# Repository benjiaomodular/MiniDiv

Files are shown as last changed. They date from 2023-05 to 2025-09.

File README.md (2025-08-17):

# MiniDiv
[][cc-by-sa]

A simple clock divider based on [HAGIWO's  design](https://note.com/solder_state/n/n7979cda44dcb).

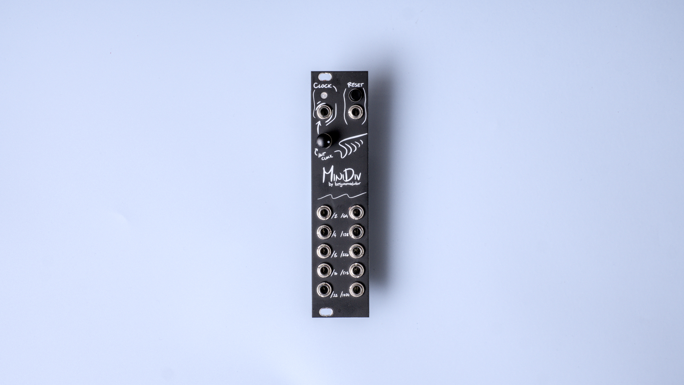
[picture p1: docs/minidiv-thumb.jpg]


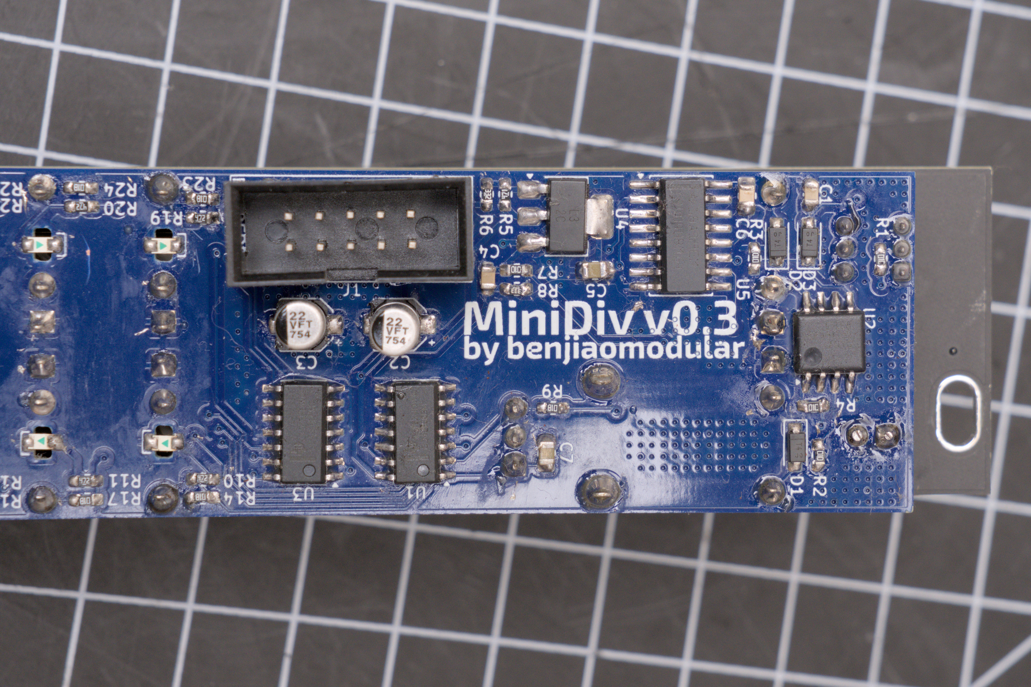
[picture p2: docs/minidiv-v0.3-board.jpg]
MiniDiv Photo


## Schematics
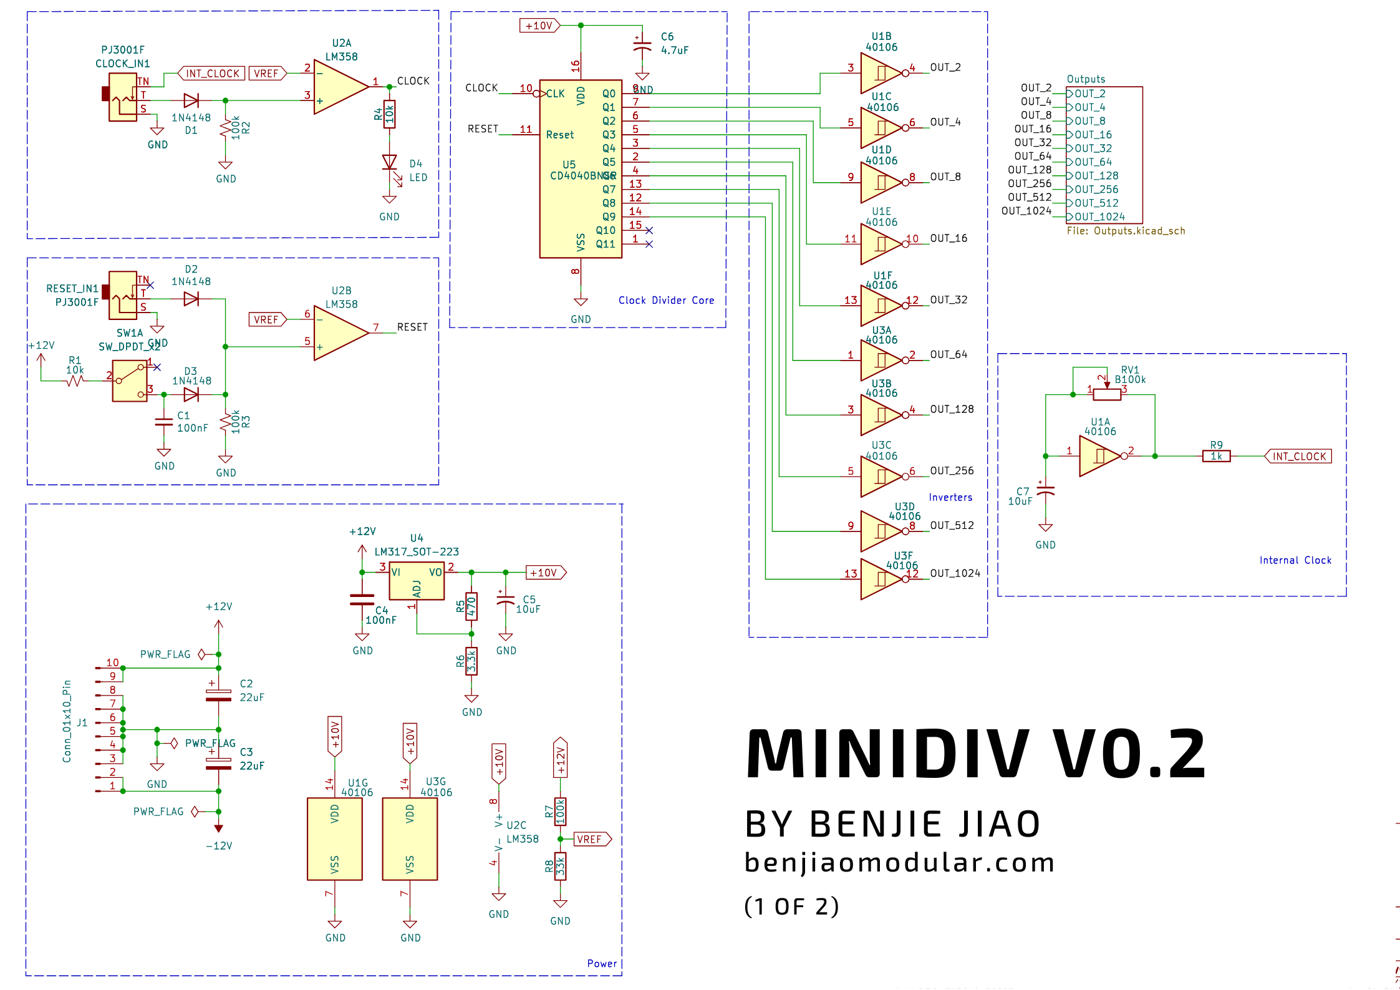
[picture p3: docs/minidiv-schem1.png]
MiniDiv Schematics

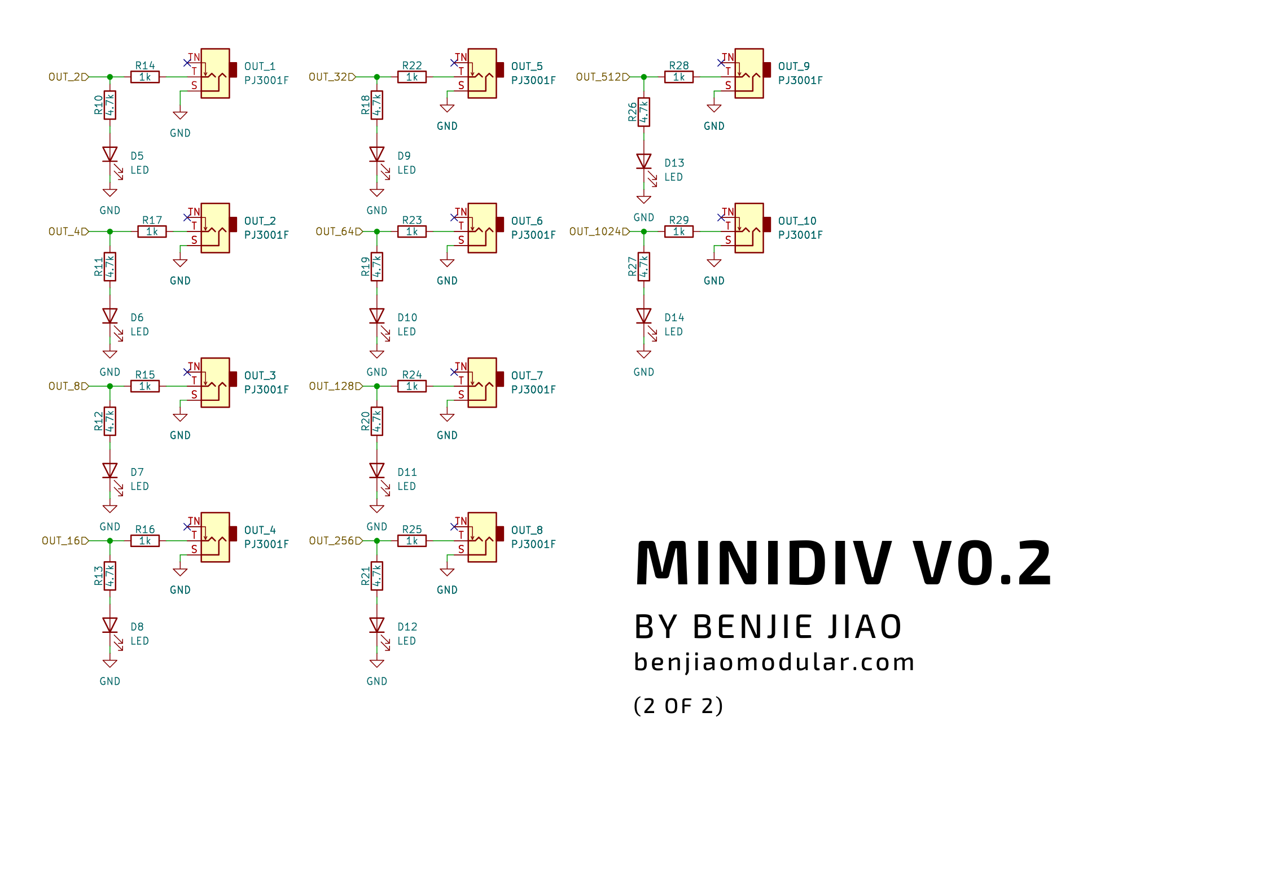
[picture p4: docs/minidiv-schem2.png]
MiniDiv Schematics


Project sponsored by [PCBWay](https://pcbway.com).

See my full docs on my website: https://benjiaomodular.com/post/2024-11-22-minidiv-pcb/

## Versions
#### v0.3 - Fixed LED clearance issue
- To address LED clearance issues, I moved the LEDs to be mounted to the back, facing down, such that the LED shines through a hole on the board. 

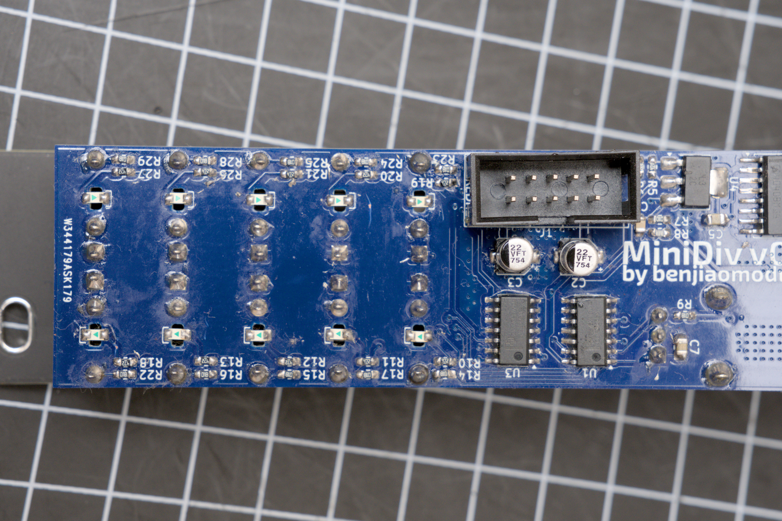
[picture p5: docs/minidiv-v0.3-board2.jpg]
MiniDiv Photo


#### v0.2 - Initial release
- First working version
- ISSUE: The LEDs were preventing the jacks from going in completly. The module still works but it might cause problems in the future.

## License

This work is licensed under a
[Creative Commons Attribution-ShareAlike 4.0 International License][cc-by-sa].

[][cc-by-sa]

[cc-by-sa]: http://creativecommons.org/licenses/by-sa/4.0/
[cc-by-sa-image]: https://licensebuttons.net/l/by-sa/4.0/88x31.png
[cc-by-sa-shield]: https://img.shields.io/badge/License-CC%20BY--SA%204.0-lightgrey.svg

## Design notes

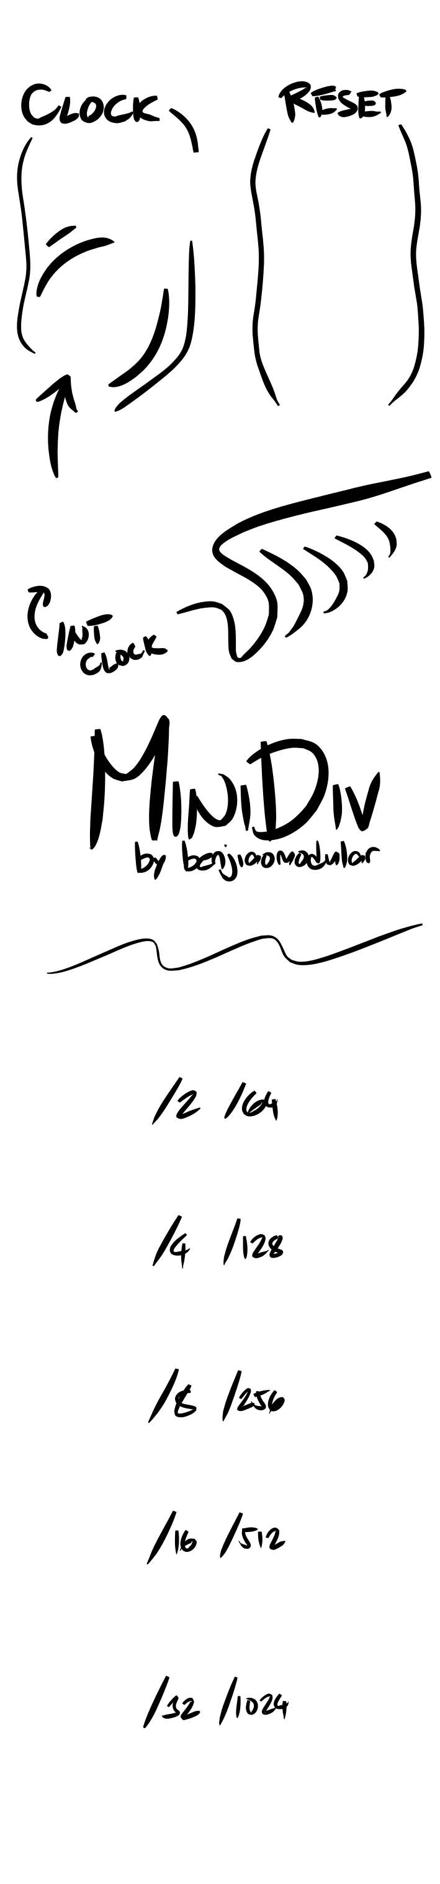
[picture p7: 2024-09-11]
hardware/panel/MiniDiv - Panel.png

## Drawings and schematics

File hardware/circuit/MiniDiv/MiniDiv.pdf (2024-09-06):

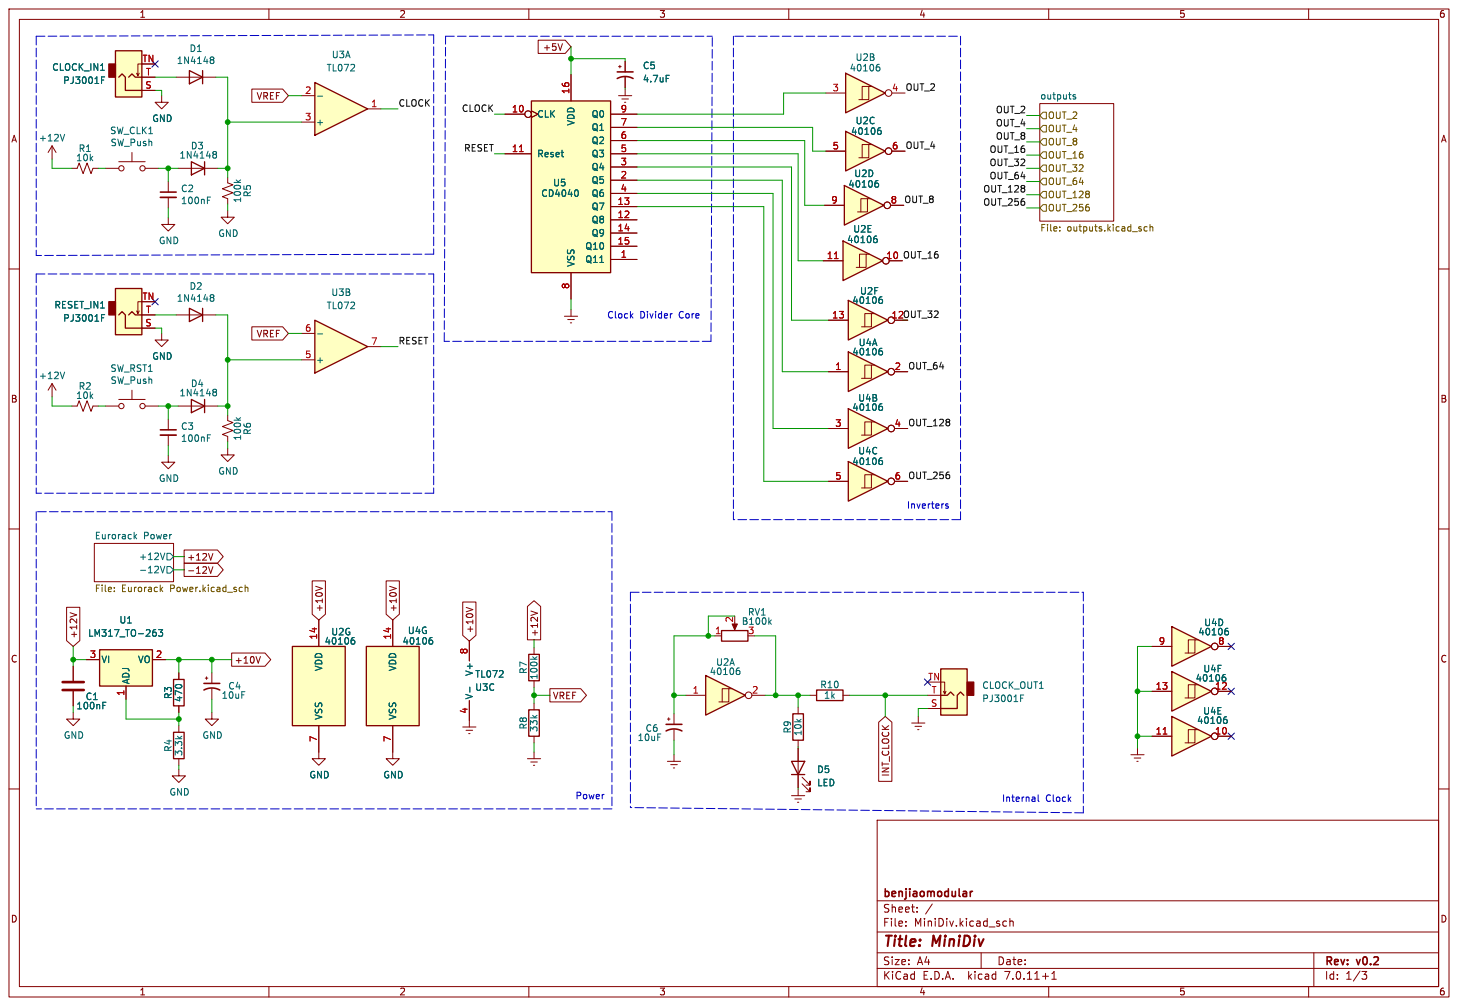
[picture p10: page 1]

File: MiniDiv.kicad_sch Sheet: / benjiaomodular

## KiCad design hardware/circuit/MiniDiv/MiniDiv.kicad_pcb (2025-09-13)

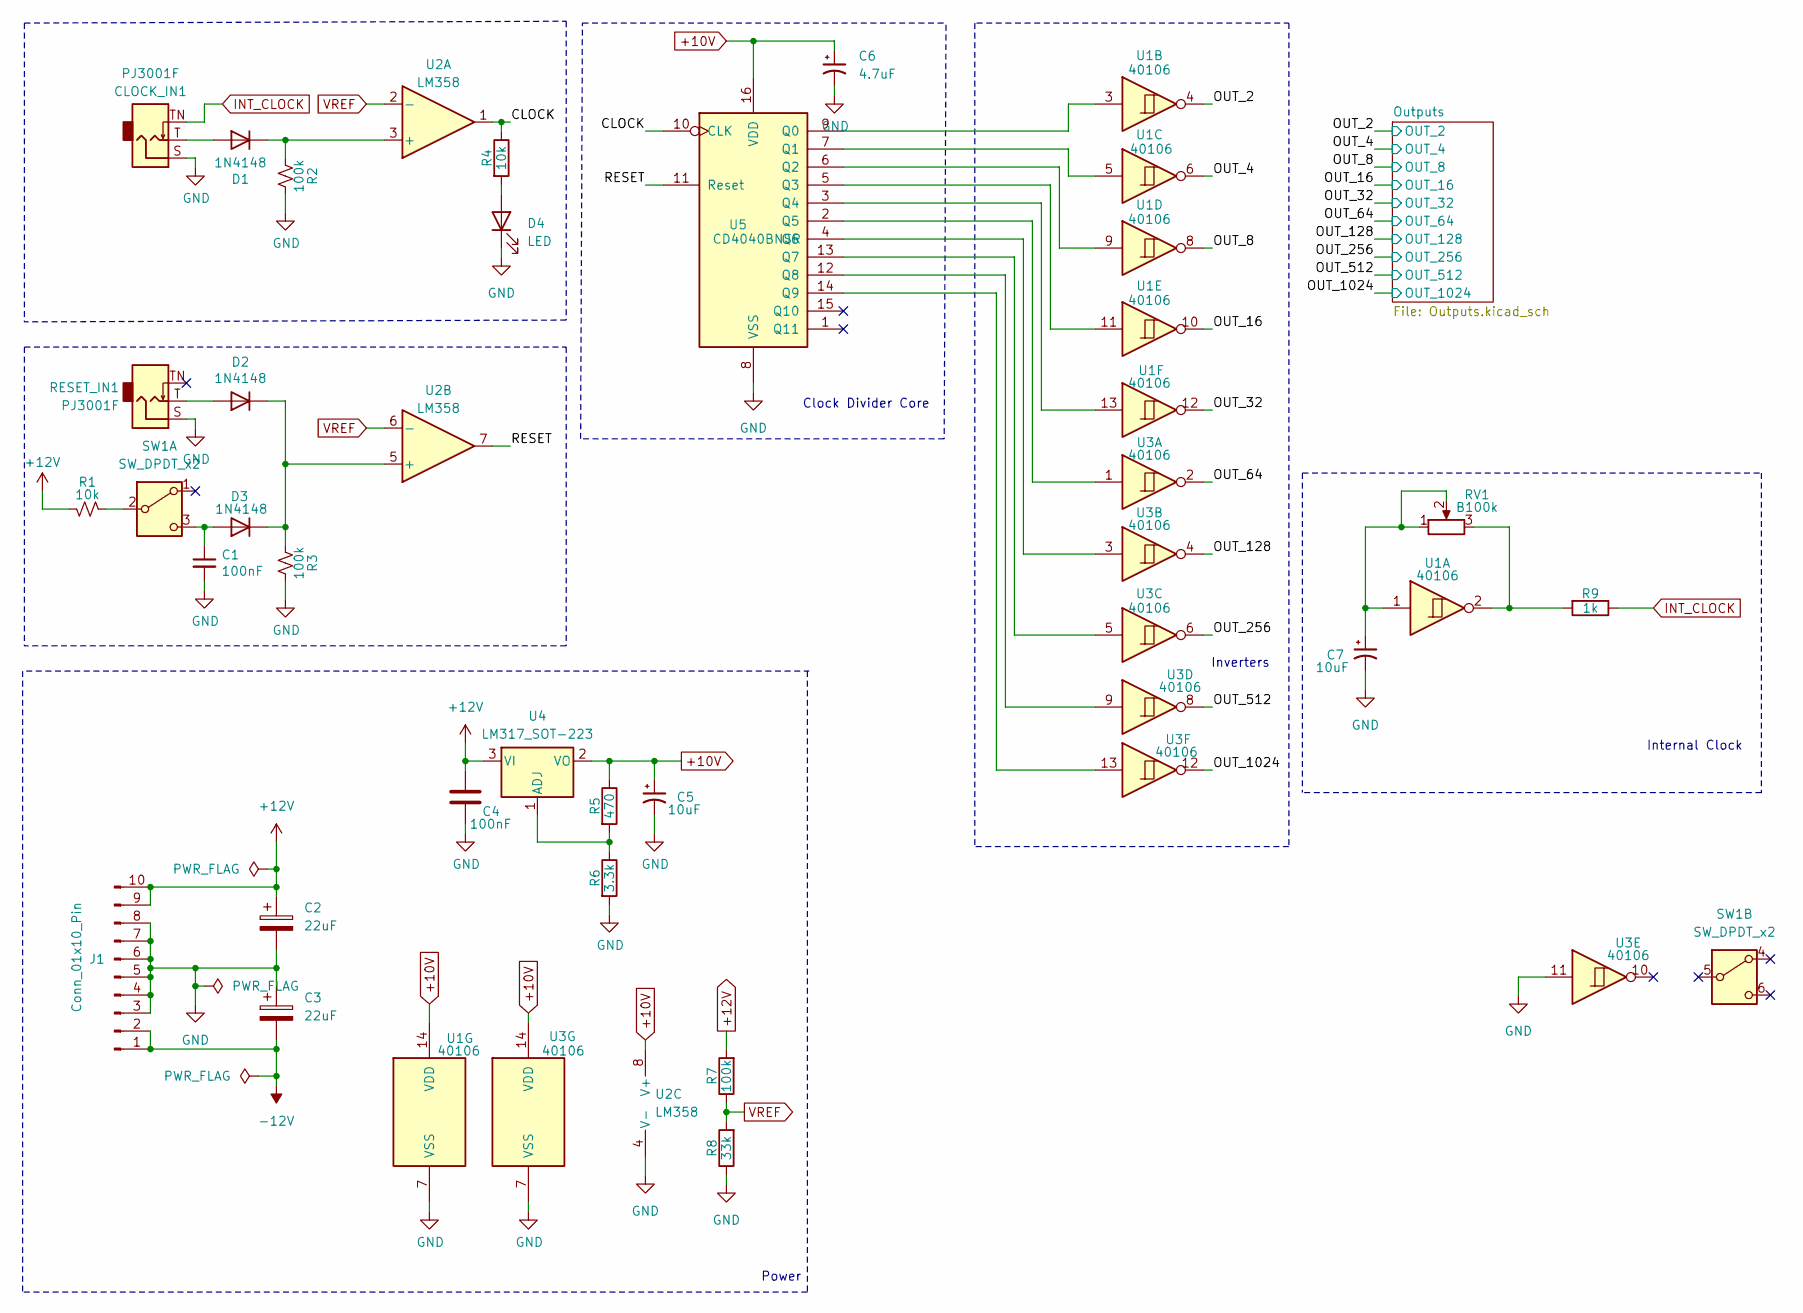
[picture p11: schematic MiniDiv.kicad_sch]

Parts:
C1: 100nF; C_0603_1608Metric_Pad1.08x0.95mm_HandSolder; Part # CC0805KRX7R9BB104
C2, C3: 22uF; CP_Elec_4x3.9; Part # EEE-FT1V220AR
C4: 100nF; C_0603_1608Metric_Pad1.08x0.95mm_HandSolder; Mfg # CC0603KRX7R8BB334; LCSC Part # C107070
C5, C7: 10uF; C_0805_2012Metric_Pad1.18x1.45mm_HandSolder; Part # TMK212BBJ106KG8T
C6: 4.7uF; C_0805_2012Metric_Pad1.18x1.45mm_HandSolder; Part # VJ0805G475KXQTW1BC
CLOCK_IN1: PJ3001F; AudioJack_3.5mm; Part # PJ-3001F
D1, D2, D3: 1N4148; D_SOD-123; Part # 1N4148WQ-7-F
D4: LED; LED_D3.0mm; Part # LED 3mm Orange
J1: Conn_01x10_Pin; Header_IDC2x05_NoArrow; Part # X9555WV-2X05-6TV01
R1, R4: 10k; R_0603_1608Metric_Pad0.98x0.95mm_HandSolder; Part # AC0603FR-0710KL
R2, R3, R7: 100k; R_0603_1608Metric_Pad0.98x0.95mm_HandSolder; Part # RC0603FR-07100KL
R5: 470; R_0603_1608Metric_Pad0.98x0.95mm_HandSolder; Part # RC0603FR-7W470RL
R6: 3.3k; R_0603_1608Metric_Pad0.98x0.95mm_HandSolder; Part # RC0603FR-7W3K3L
R8: 33k; R_0603_1608Metric_Pad0.98x0.95mm_HandSolder; Part # CR0603-FX-3302ELF
R9: 1k; R_0603_1608Metric_Pad0.98x0.95mm_HandSolder; Part # RC0603FR-071KL
RESET_IN1: PJ3001F; AudioJack_3.5mm; Part # PJ-3001F
RV1: B100k; Potentiometer_RV09; Part # RV09AF-40-20K-B100K
SW1: SW_DPDT_x2; Button_KFC7x7; Part # KFC7x7 Momentary
U1, U3: 40106; SOIC-14_3.9x8.7mm_P1.27mm; Part # Texas Instruments
U2: LM358; SOIC-8_5.23x5.23mm_P1.27mm; Part # Texas Instruments
U4: LM317_SOT-223; SOT-223-3_TabPin2; Part # Texas Instruments
U5: CD4040BNSR; SOIC-16W_5.3x10.2mm_P1.27mm; Part # Texas Instruments

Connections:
+10V: C5.1, C6.1, R5.1, U1.14 (VDD), U2.8 (V+), U3.14 (VDD), U4.2 (VO), U5.16 (VDD)
+12V: C2.1, C4.1, J1.9, J1.10, R1.1, R7.2, U4.3 (VI)
-12V: C3.2, J1.1, J1.2
/CLOCK: R4.1, U2.1, U5.10 (CLK)
/OUT_2: U1.4; also elsewhere on the board
/OUT_4: U1.6; also elsewhere on the board
/OUT_8: U1.8; also elsewhere on the board
/OUT_16: U1.10; also elsewhere on the board
/OUT_32: U1.12; also elsewhere on the board
/OUT_64: U3.2; also elsewhere on the board
/OUT_128: U3.4; also elsewhere on the board
/OUT_256: U3.6; also elsewhere on the board
/OUT_512: U3.8; also elsewhere on the board
/OUT_1024: U3.12; also elsewhere on the board
/RESET: U2.7, U5.11 (Reset)
GND: C1.2, C2.2, C3.1, C4.2, C5.2, C6.2, C7.2, CLOCK_IN1.S, D4.1 (K), J1.3, J1.4, J1.5, J1.6, J1.7, J1.8, R2.1, R3.1, R6.2, R8.1, RESET_IN1.S, U1.7 (VSS), U2.4 (V-), U3.7 (VSS), U3.11, U5.8 (VSS); also elsewhere on the board
INT_CLOCK: CLOCK_IN1.TN, R9.1
unnamed: C7.1, RV1.1, RV1.2, U1.1
unnamed: CLOCK_IN1.T, D1.2 (A)
unnamed: D1.1 (K), R2.2, U2.3 (+)
unnamed: D2.2 (A), RESET_IN1.T
unnamed: D2.1 (K), D3.1 (K), R3.2, U2.5 (+)
unnamed: C1.1, D3.2 (A), SW1.3 (C)
unnamed: D4.2 (A), R4.2
unnamed: R9.2, RV1.3, U1.2
unnamed: R1.2, SW1.2 (B)
unnamed: R5.2, R6.1, U4.1 (ADJ)
unnamed: U1.3, U5.9 (Q0)
unnamed: U1.5, U5.7 (Q1)
unnamed: U1.9, U5.6 (Q2)
unnamed: U1.11, U5.5 (Q3)
unnamed: U1.13, U5.3 (Q4)
unnamed: U3.1, U5.2 (Q5)
unnamed: U3.3, U5.4 (Q6)
unnamed: U3.5, U5.13 (Q7)
unnamed: U3.9, U5.12 (Q8)
unnamed: U3.13, U5.14 (Q9)
VREF: R7.1, R8.2, U2.2 (-), U2.6 (-)

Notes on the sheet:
Internal Clock
Clock Divider Core
Power
Inverters

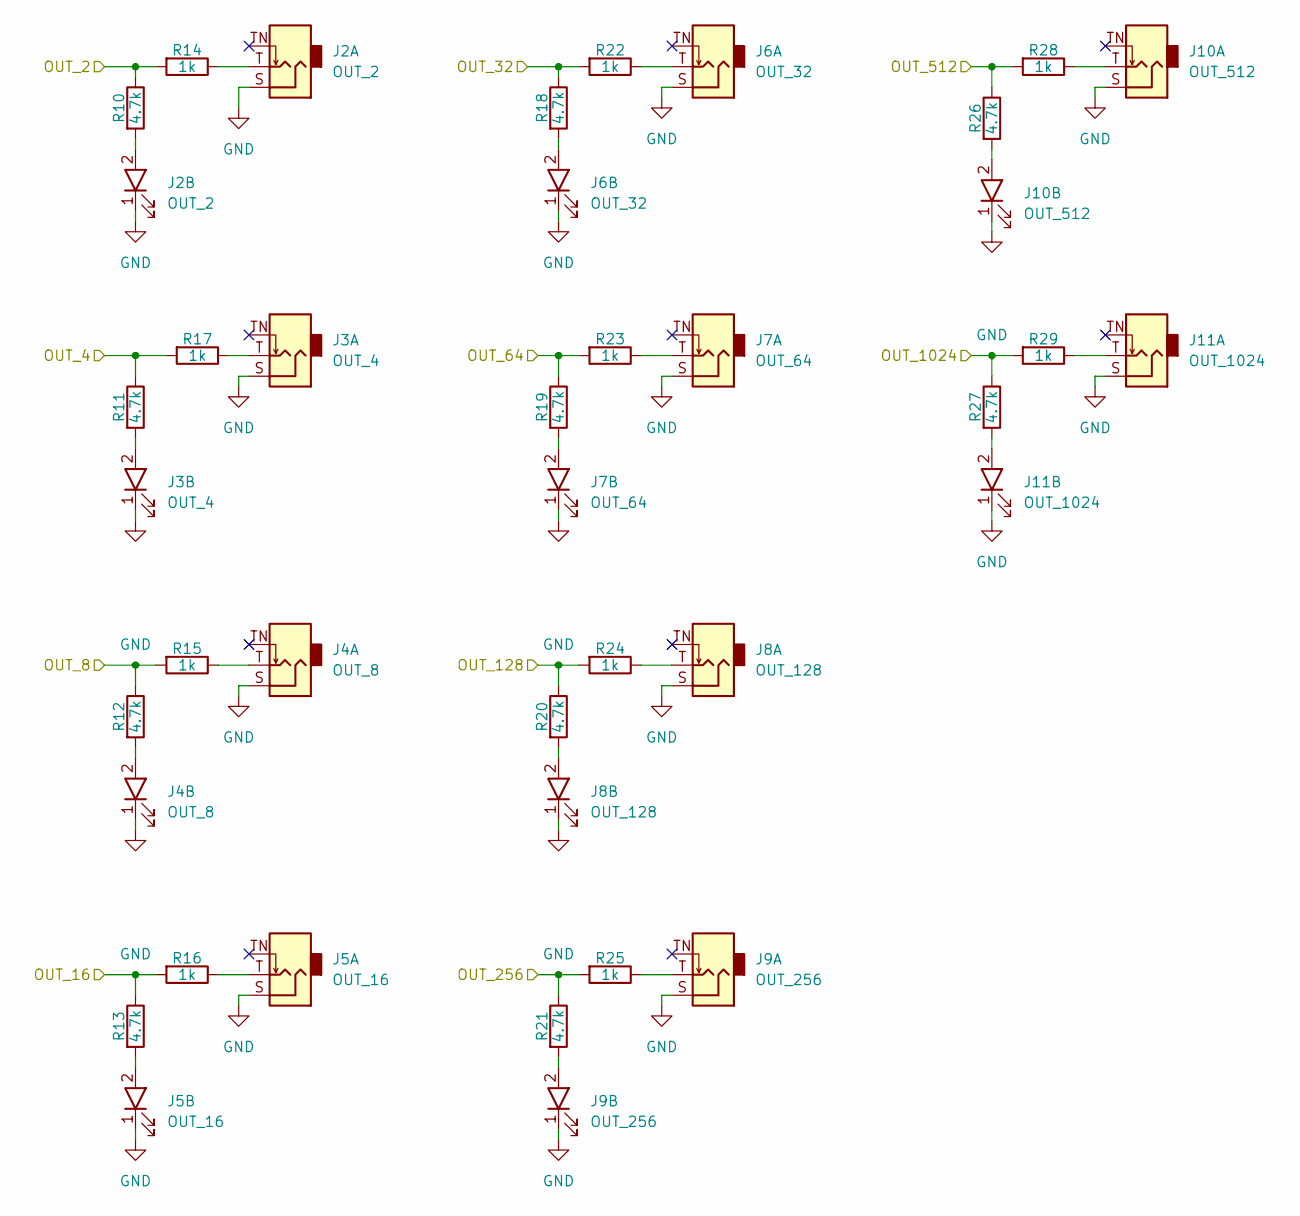
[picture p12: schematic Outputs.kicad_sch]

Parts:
J2: OUT_2; AudioJack_PJ3001F_0805LED
J3: OUT_4; AudioJack_PJ3001F_0805LED
J4: OUT_8; AudioJack_PJ3001F_0805LED
J5: OUT_16; AudioJack_PJ3001F_0805LED
J6: OUT_32; AudioJack_PJ3001F_0805LED
J7: OUT_64; AudioJack_PJ3001F_0805LED
J8: OUT_128; AudioJack_PJ3001F_0805LED
J9: OUT_256; AudioJack_PJ3001F_0805LED
J10: OUT_512; AudioJack_PJ3001F_0805LED
J11: OUT_1024; AudioJack_PJ3001F_0805LED
R10, R11, R12, R13, R18, R19, R20, R21, R26, R27: 4.7k; R_0603_1608Metric_Pad0.98x0.95mm_HandSolder; Part # RC0603FR-074K7L
R14, R15, R16, R17, R22, R23, R24, R25, R28, R29: 1k; R_0603_1608Metric_Pad0.98x0.95mm_HandSolder; Part # RC0603FR-071KL

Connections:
/OUT_2: R10.1, R14.2; also elsewhere on the board
/OUT_4: R11.1, R17.2; also elsewhere on the board
/OUT_8: R12.1, R15.2; also elsewhere on the board
/OUT_16: R13.1, R16.2; also elsewhere on the board
/OUT_32: R18.1, R22.2; also elsewhere on the board
/OUT_64: R19.1, R23.2; also elsewhere on the board
/OUT_128: R20.1, R24.2; also elsewhere on the board
/OUT_256: R21.1, R25.2; also elsewhere on the board
/OUT_512: R26.1, R28.2; also elsewhere on the board
/OUT_1024: R27.1, R29.2; also elsewhere on the board
GND: J2.1, J2.S, J3.1, J3.S, J4.1, J4.S, J5.1, J5.S, J6.1, J6.S, J7.1, J7.S, J8.1, J8.S, J9.1, J9.S, J10.1, J10.S, J11.1, J11.S; also elsewhere on the board
unnamed: J2.2, R10.2
unnamed: J2.T, R14.1
unnamed: J3.2, R11.2
unnamed: J3.T, R17.1
unnamed: J4.2, R12.2
unnamed: J4.T, R15.1
unnamed: J5.2, R13.2
unnamed: J5.T, R16.1
unnamed: J6.2, R18.2
unnamed: J6.T, R22.1
unnamed: J7.2, R19.2
unnamed: J7.T, R23.1
unnamed: J8.2, R20.2
unnamed: J8.T, R24.1
unnamed: J9.2, R21.2
unnamed: J9.T, R25.1
unnamed: J10.2, R26.2
unnamed: J10.T, R28.1
unnamed: J11.2, R27.2
unnamed: J11.T, R29.1

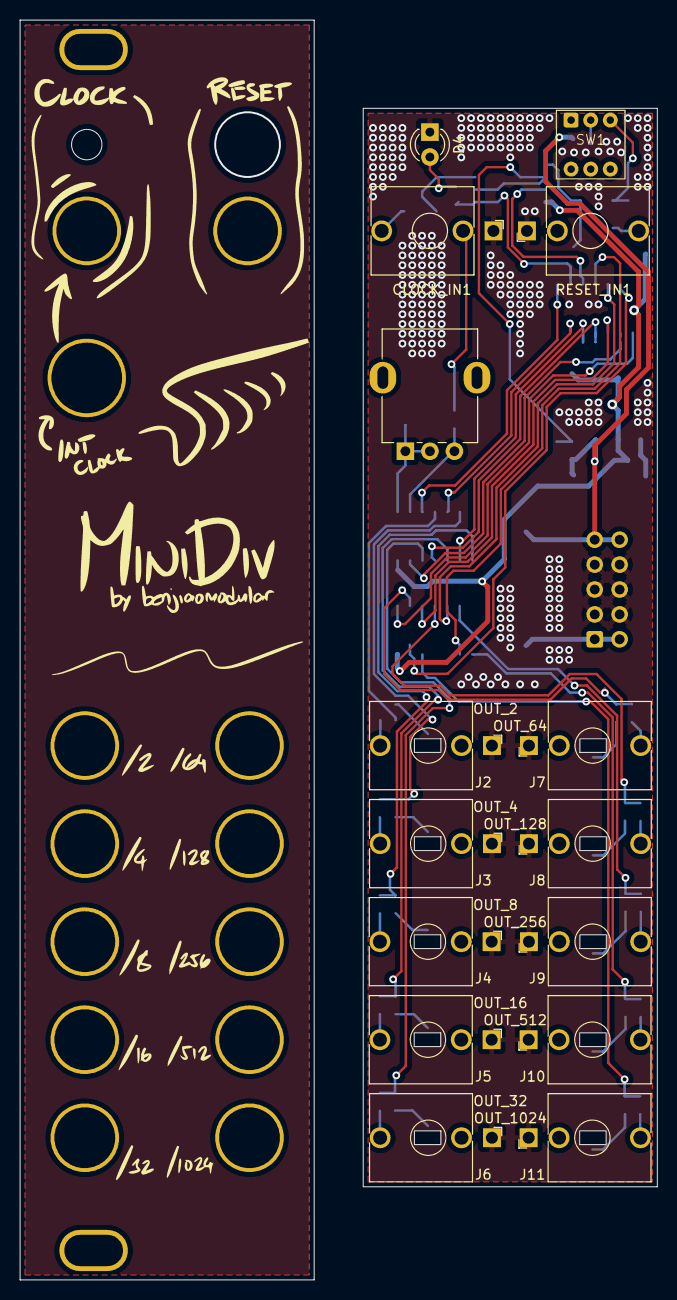
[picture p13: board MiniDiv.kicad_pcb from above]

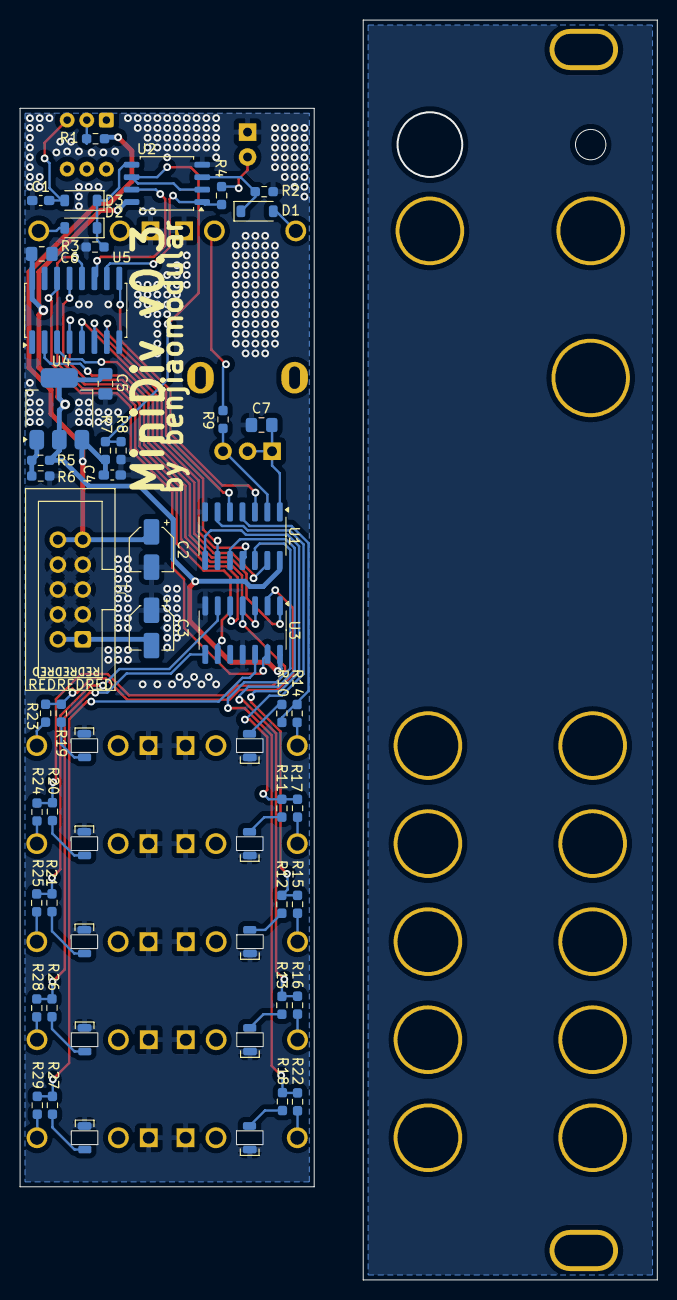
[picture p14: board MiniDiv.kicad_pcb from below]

Board: 2 copper layers, 30.0 x 110.0 mm, 60 parts (45 on the bottom side), 58 nets.

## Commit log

2023-05-26 Added schematics
2023-09-12 Updated schematics
    [MiniDiv.kicad_sch]
2024-09-06 reorganized, updated license, finalized 0.2 circuit
    [Eurorack Power.kicad_sch, MiniDiv.kicad_pcb, MiniDiv.kicad_sch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]
2024-09-07 reorganized, schem ready for pcb
    [Eurorack Power.kicad_sch, MiniDiv.kicad_sch, Outputs.kicad_sch]
2024-09-11 v0.2 PCB
    [MiniDiv v0.2 - Main.kicad_pcb, MiniDiv v0.2 - Panel.kicad_pcb, MiniDiv.kicad_sch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]
2024-10-28 Updated PCBs
    [MiniDiv v0.2 - Main.kicad_pcb, MiniDiv v0.2 - Panel.kicad_pcb, MiniDiv.kicad_pcb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]
2024-11-21 updated bom
    [MiniDiv.kicad_pcb, MiniDiv.kicad_sch]
2024-11-21 Added drawings and photos
    [MiniDiv.kicad_pcb, MiniDiv.kicad_sch, Outputs.kicad_sch]
2024-11-21 Fixed button to momentary
    [MiniDiv.kicad_pcb, MiniDiv.kicad_sch]
2025-08-17 Fixed LED clearance issues
    [MiniDiv v0.3 - Front-B_Cu.gbr, MiniDiv v0.3 - Front-B_Mask.gbr, MiniDiv v0.3 - Front-B_Paste.gbr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]
2025-09-13 Updated v0.3 BOMs
    [MiniDiv.kicad_pcb, MiniDiv.kicad_sch, Outputs.kicad_sch]

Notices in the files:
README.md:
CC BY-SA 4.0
